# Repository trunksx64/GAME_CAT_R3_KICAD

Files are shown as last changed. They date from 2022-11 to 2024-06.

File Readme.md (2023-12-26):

# Game//Cat ::: Revisión R3 :: Versión 3.50

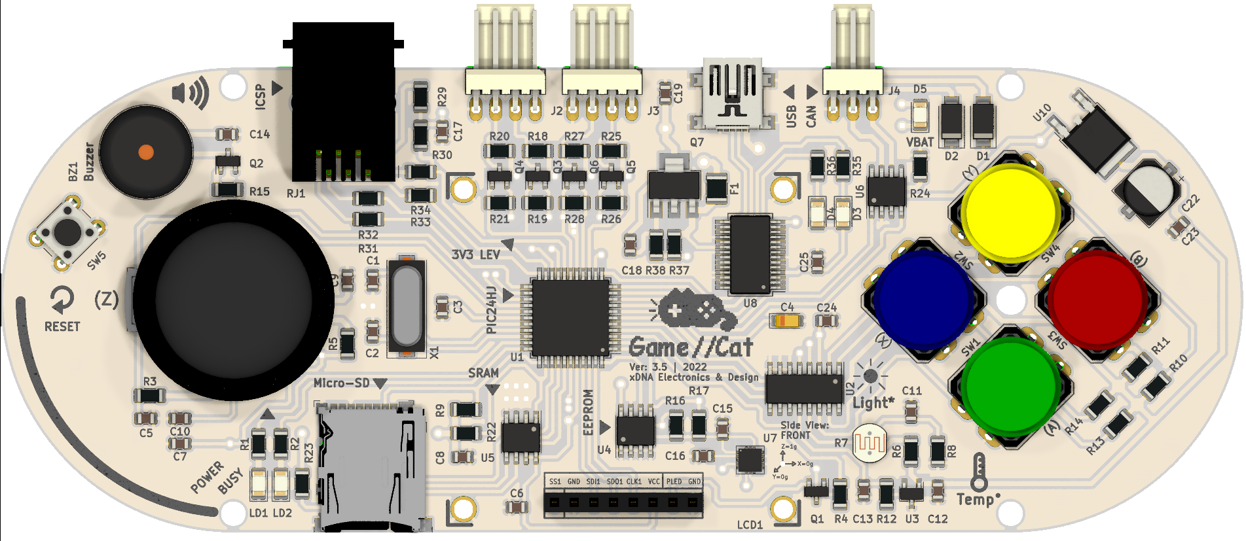
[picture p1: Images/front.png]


## Razón de Ser e Inspiración

Este Control se basa en la Idea Original del Game//Cat Version R2, el cual a su vez se inspira en el diseño del joystick y botones del Arduino Esplora. El primer Control se implementó para ser usado como parametrizador y las siguientes revisiones se presentó como Tesis de Grado de Especialización de Instrumentación Industrial que curse. Se Utilizó principalmente como Herramienta de Programación para Tarjeta de Control de Ascensores Usando Un Firmware de Codito Cerrado. Se Implementó FREERTOS para su uso, así como librerías Básicas en MPLABX y XC16. La idea principal es utilizar los Microcontroladores de 16Bits de Microchip con periféricos listos y configurados. Es pequeño y Portable, ideal para llevar a todo lado, no intenta competir con controles similares a Arduino. Se desea implementar a futuro un Bootloader tanto por USB, RS232, SD y CAN.

Inicialmente, se Requiere un Programador Basado en PICKIT2/ICD3, MPLAB C30 Y MPLAB V4.0 como mínimo. 

En la Actualidad se recomienda el MPLAB SNAP, XC16 y MPLABX V6.0 

Algunos Elementos "Footprints" y "Symbols" están basados en mis librerías, cuáles encontrarán en este mismo Repositorio.

## Características del Hardware

  * Microcontrolador PIC24HJ128GP504.
  * Pantalla LCD PCD8544 (Based Nokia GLCD) - SPI.
  * Joystick Análogo de 2 ejes + Botón Digital.
  * 4 Botones Digitales.
  * Accelerometro - MMA8452Q - I2C. 
  * Sensor de Temperatura (LM61).
  * Sensor de Luz (LDR).
  * Memoria Eeprom 24LCXXX - I2C.
  * Memoria Ram 23KXX - SPI.
  * Ranura Memoria Micro-SD - SPI.
  * Buzzer por PWM.
  * Conexión USB - FTDI-RL232/UART - 5V.
  * Conexión CAN 5V.
  * 2 LED´s de Actividad.
  * Salidas Para PWM y UART - Con figurables - 3.3V.
  * Conexión ICSP con línea AUX, para control extra de puerto.
  * Cargador de Batería Lipo (MCP73831) con Indicador LED.

## Características Específicas

  * Debido a que el PIC trabaja a 3.3V, el uso del PCA82C251 y el FTDI-RL232 está a 5V, alimentado directamente por el Control USB, el FTDI-RL232 se encarga de "gestionar" la alimentación del sistema proporcionando un arranque suave en la tensión, luego se pasa por un regulador de 3,3V para alimentar el resto de componentes.
  * Para Potabilidad he agregado un control para la carga de Baterías de tipo Lipo, este gobernado él con el CI MCP73831, el cual mediante el uso del Mosfet DMP1045, intercambia la alimentación proveniente del FTDI-RL232 y la Batería según el estado de conexión USB, se puede usar Baterías de 3,7V en adelante hasta un máximo de 6V, cuando el Game//Cat está usando la Batería, el FTDI-RL232 se deshabilita.
  * Para el Manejo del Joystick, Botones, Sensor de Temperatura y Luz. He empleado el CI-74HC4051, que es un Multiplexor Análogo para leer los Valores por el módulo ADC, el cual puede utilizarse de 10 o 12Bits en conjunto con un canal DMA si fuere necesario.
  * La Comunicación UART, es una Salida/Entrada dedicada con un conversor de tensión de 3.3V a 5V de forma bidireccional con transistores Mosfet, con el fin de proteger y poder comunicar el PIC24H con cualquier tipo de dispositivo.
  * La Comunicación USB se hace por medio del CI FTDI-RL232, esto es porque el PIC no posee dicho Módulo y además permite ahorrar en la Memoria del PIC el Stack del USB, esto permite que sea Conectar y Usar, puesto que los Drives de este USB son reconocidos de forma inmediata por Windows y Linux sin problemas.
  * La Comunicación CAN la he Incluido porque en estos momentos trabajo con esta interfase y su popularidad ha crecido bastante, por experiencia este BUS es muy robusto y fácil de usar, en el PIC se hace uso de dos canales DMA teniendo una respuesta bastante rápida y sin sacrificar la memoria RAM principal, su conexión se hace por medio del Transeiver PCA82C251, además he agregado un par de diodos TVH para proteger dicho CI.
  * La Ranura para la Tarjeta Micro-SD, posee conexión con el Módulo SPI, el cual está compartida con la Memoria Ram 23Kxxx, Además la pantalla posee también una conexión al segundo Módulo SPI, que puede usarse para "colgar" otros dispositivos si no vamos a usar la Pantalla.
  * El control del Buzzer se ha dejado por un Pin que puede ser utilizado tanto por el módulo PWM o un pin Común, su uso dependerá del Programa o Aplicación.
  * Posee una Memoria I2C en conjunto con un Accelerometro, con comunicación directa.
  * La programación se hace por medio de la conexión ICSP o Bootloader por USB, usando cualquier programador, PICKIT2-3 y/ó ICD2-3, igual estas salidas pueden usarse como cualquier puerto, teniendo presente que no poseen ninguna protección a tensiones superiores de 3,3V.
  * Ya por Último, he dejado dos visualiza-dores, que son libres de uso.

Básicamente, esto es el GAME//CAT, una tarjeta más que un sistema de control para usuarios avanzados, es una tarjeta de entrenamiento para los principiantes, puesto que todo lo que incluye hace uso forzoso de todo los controles que el PIC24HJ128GP504 incorpora.

## Microcontrolador

* Architecture 16-bit.
* CPU Speed Max. 40 MIPS.
* Memory Type Flash.
* Program Memory 128Kb.
* RAM 8,192 Bytes.
* Temperature Range C -40 to 150.
* Operating Voltage Range (V) 3 to 3.6.
* I/O Pins 35 & Pin Count 44.
* Internal Oscillator 7.37 MHz, 32.768 kH.
* Digital Communication Peripherals 2-UART, 2-SPI,1-I2C, 1-CAN.
* Comparators 2, Capture/Compare/PWM Peripherals 4/4, PWM Resolution bits 16.
* Timers 5 x 16-bit 2 x 32-bit.
* Parallel Port PMP(No Usado), Hardware RTCC-1 (No Usado).
* Chanel DMA-8.
* Cap Touch Channels-13 (No Usado).

## Versiones

* 2017 : 1.0.0 : Primera Versión en Kicad 4
* 2017 : 1.2.0 : Se Agregó Conversión de Tensión 5V a 3.3V Bidireccional en salida UART y PWM, se eliminó conexión DC externa.
* 2018 : 2.0.0 : Se Migró completamente a Kicad 5, el Led control se removió para dar opción de selección de Periférico SPI (Ram y SD).
* 2018 : 2.1.0 : Se rediseñó y corrigió error en botón del Joystick, se corrigió el trucado de líneas de Programación PGM y PGD.
* 2018 : 2.2.0 : Se Agregó Resistencias de protección (0Ohm) en entradas Jack RJ11 de Programación.
* 2018 : 2.1.0 : Se Agregó y Calibro Resistencia del Botón de Reset, se agregó control se Carga para Bateria Lipo 3.3V.
* 2018 : 2.5.0 : Se Actulizaron Logos de la Marca y de Hardware Libre, se Actualizó a licencia Creative Commons V4.
* 2018 : 2.7.0 : Se Actualizaron las Librerías de Módulos de Kicad, basadas en Progetti Walter.
* 2018 : 2.9.0 : Se Agregaron condensadores de filtrado al multiplexor análogo, se cambiaron los botones por diseño con poste.
* 2019 : 2.9.1 : Se Organizaron los Archivos para Hospedarlos en Github, Se Ordenaron condensadores y Cristal del PIC.
* 2021 : 2.9.1 : Se Actualiza a KiCad 6 todos los archivos y Librerías.
* 2022 : 3.0.0 : Se Actualizaron los Valores de las resistencias del conversor de 5V-3.3V de un 1K a 10K.
* 2022 : 3.1.0 : Se reestructuró completamente los esquemáticos y se usaron páginas separadas para cada Módulo.
* 2022 : 3.2.0 : Se corrigieron errores en los anchos de pista y reubicaron varios elementos como Seregrafia.
* 2022 : 3.3.0 : Se Actualizaron los conectores Moles para cuatros Salidas, sumando VCC y GND para alimentar controles externos.
* 2022 : 3.5.0 : Se Actualizaron los Logos y posiciones de Seregrafia de Varios componentes.

## ERRATAS

* Debido a tolerancia de tensión del MCP2551, no es posible usarlo para tensiones de 3.3V, cuál hacer imposible usar el CANBUS, sé recomienda usar el PCA82C251 cuál soportar desde 1.8V hasta 24V.

## Créditos

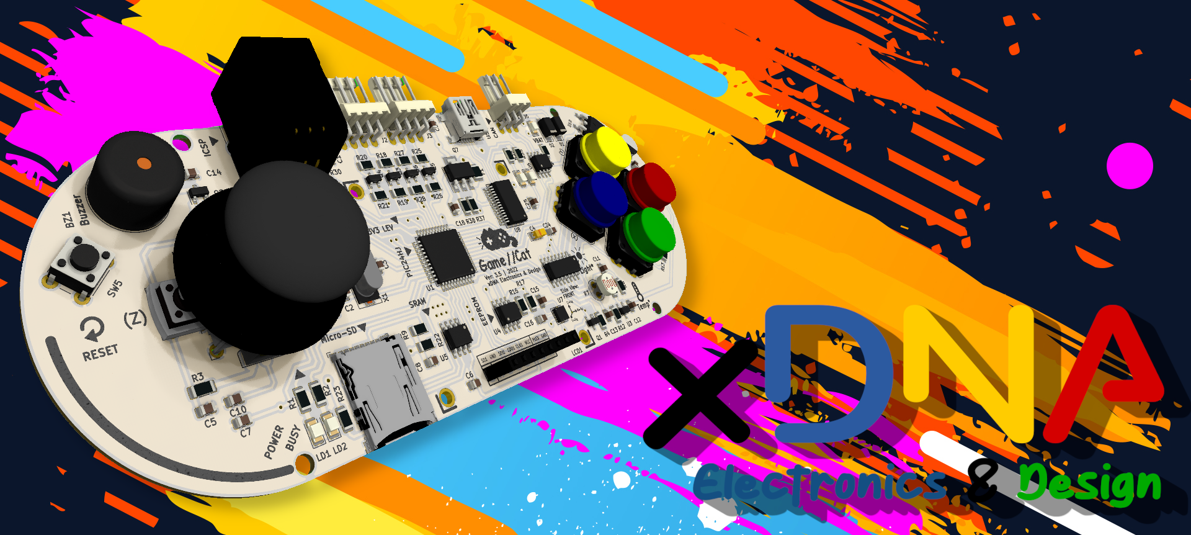
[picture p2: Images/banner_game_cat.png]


xDNA Electronics & Desing es una microempresa Personal, que se dedica y encarga de elaborar proyectos de Control y Automatización por pedido, su idea es colaborar y ayudar a quines a si lo requieran, el proyecto se hizo principalmente como Hobby el cual gracias a terceros se pudo implementar y hacer su creación, por lo cual se da la libertad de usarlo para experimentar sin hacer uso comercial del mismo.

## Licencia

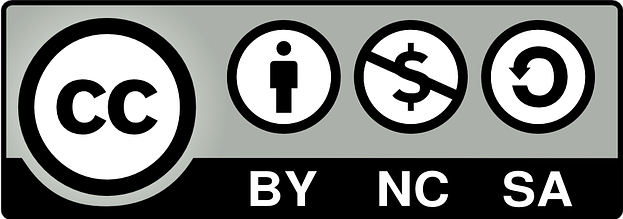
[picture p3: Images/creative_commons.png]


Licensed under Attribution-NonCommercial-ShareAlike 4.0 International (CC BY-NC-SA 4.0)

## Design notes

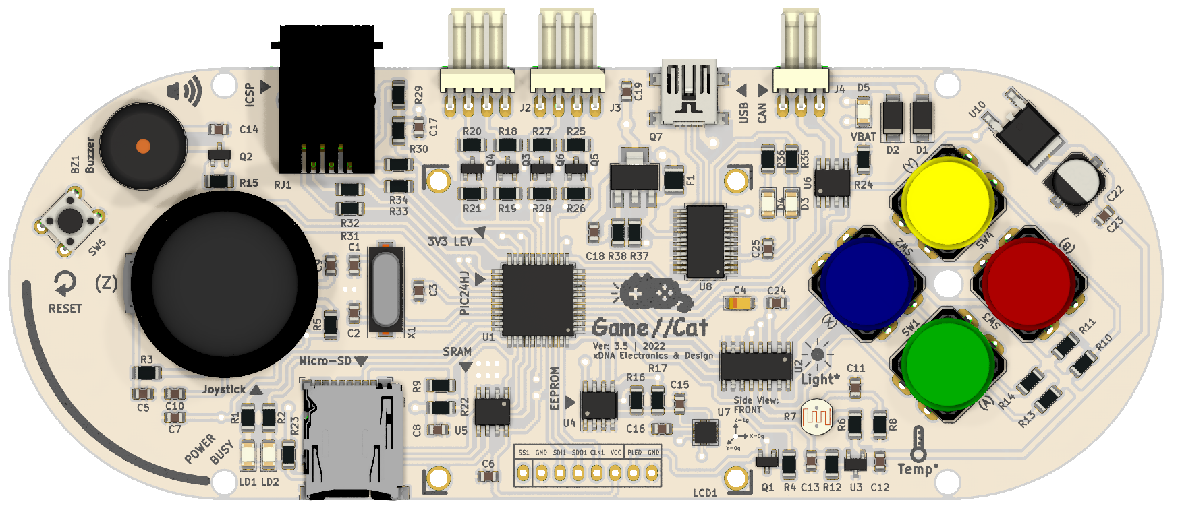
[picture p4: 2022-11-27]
Game_Cat_R3.png

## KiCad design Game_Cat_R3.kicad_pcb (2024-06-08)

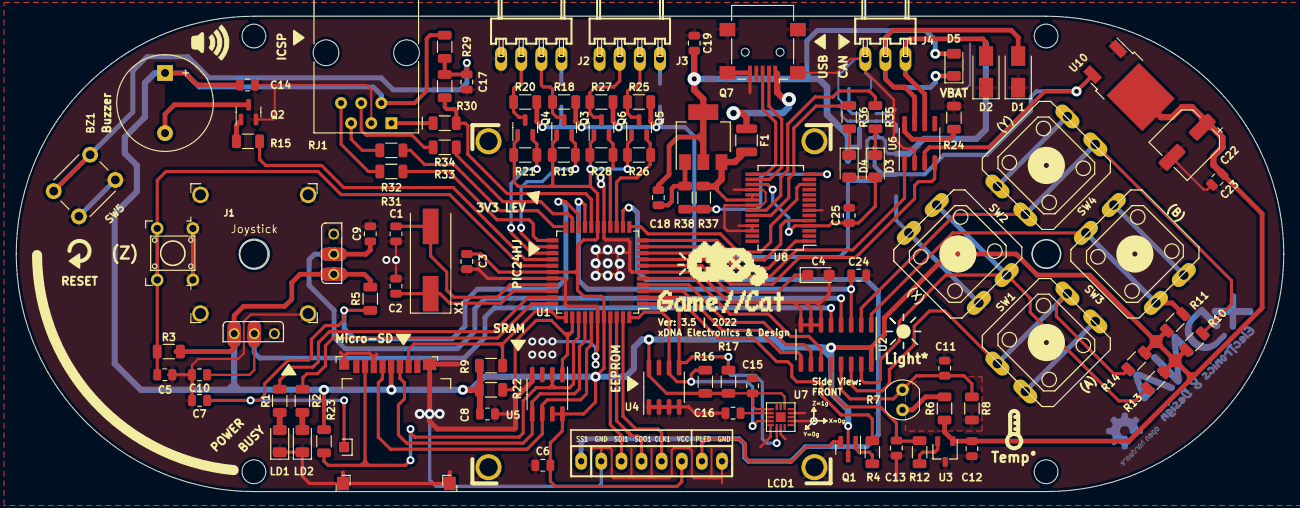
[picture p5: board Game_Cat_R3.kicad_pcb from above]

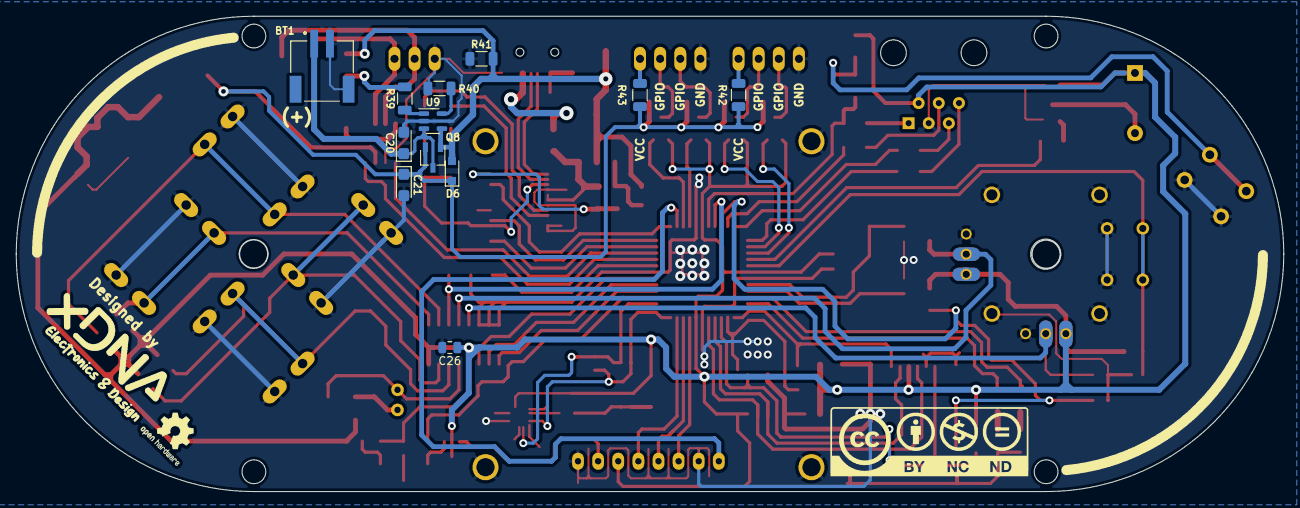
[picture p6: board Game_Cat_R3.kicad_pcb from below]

Board: 2 copper layers, 160.0 x 60.0 mm, 113 parts (12 on the bottom side), 87 nets.

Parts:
BT1: 3V7; Connector_1x02_P2.0mm
BZ1: Buzzer; Buzzer_12x9.5RM7.6
C1, C2: 22pF; C_0805_2012Metric
C3, C25: 100uF; C_0805_2012Metric
C4: 10uF; CP_EIA-3216-18_Kemet-A
C5, C7, C9, C10, C24, C26: 10pF; C_0805_2012Metric
C6, C8, C11, C12, C14, C15, C16: 10nF; C_0805_2012Metric
C13, C17, C18, C19, C23: 100nF; C_0805_2012Metric
C20: 4.7uF; CP_EIA-3216-18_Kemet-A
C21: 1uF; CP_EIA-3216-18_Kemet-A
C22: 100uF; CP_Elec_6.3x4.5
D1, D2: D_TVS; D_SMA
D3, D4: LED; LED_1206_3216Metric
D5: VBAT; LED_1206_3216Metric
D6: BAT60J; D_SOD-323_HandSoldering
F1: Fuse; R_1210_3225Metric
J1: Joystick; JOYSTICK_TUMB
J2: UART; MOLEX_KK_1x04_P2.54mm_HORIZONTAL
J3: PWM; MOLEX_KK_1x04_P2.54mm_HORIZONTAL
J4: CAN; MOLEX_KK_1x03_P2.54mm_HORIZONTAL
LCD1: PCD8544-BASE; GLCD_PCD8544_BASE
LD1: POWER; LED_1206_3216Metric
LD2: BUSY; LED_1206_3216Metric
Q1: MMBT3906; SOT-23
Q2: MMBT3904; SOT-23
Q3, Q4, Q5, Q6: BSS138; SOT-23
Q7: IRFL901; SOT-223
Q8: NTR1P02LT1G; TSOT-23
R1, R2, R35: 330R; R_1206_3216Metric
R3, R4, R5, R6, R8, R10, R11, R12, R13, R14, R18, R19, R20, R21, R25, R27, R28, R29, R37, R40: 10K; R_1206_3216Metric
R7: VT93xx; R_LDR_4.9x4.2mm_P2.54mm_Vertical
R9, R15, R22, R23, R24, R26, R38, R42, R43: 1K; R_1206_3216Metric
R16, R17: 4K7; R_1206_3216Metric
R30, R39: 470R; R_1206_3216Metric
R31, R32, R33, R34: 0R; R_1206_3216Metric
R36: 33OR; R_1206_3216Metric
R41: 100K; R_1206_3216Metric
RJ1: RJ12; RJ12_Horizontal
Ref**: GameCatPixel; xdna_game_cat_logo_skill_pixel
SD1: Micro-SD; MICRO_SD_HC_DM3AT
SW1: (A); SW_PUSH_PTS_125x12mm_SNAP_GREEN
SW2: (X); SW_PUSH_PTS_125x12mm_SNAP_BLUE
SW3: (B); SW_PUSH_PTS_125x12mm_SNAP_RED
SW4: (Y); SW_PUSH_PTS_125x12mm_SNAP_YELLOW
SW5: RESET; SW_PUSH_6mm_H5mm
U1: PIC24HJXXXGPX04_TQFP; TQFP-44_10x10mm_P0.8mm
U2: 74HC4051; SOIC-16_3.9x9.9mm_P1.27mm
U3: LM61; TSOT-23
U4: M24C512; SOIC-8_3.9x4.9mm_P1.27mm
U5: 23KXX; SOIC-8_3.9x4.9mm_P1.27mm
U6: PCA82C251; SOIC-8_3.9x4.9mm_P1.27mm
U7: MMA8452Q; QFN_16_3x3x1mm_P0.5mm
U8: FT232RL; SSOP-28_5.3x10.2mm_P0.65mm
U9: MCP73831; SOT-23-5
U10: LM1117; TO-252-2
USB1: USB_B_Micro; USB_Mini-B_Lumberg_2486_01_Horizontal
X1: 4Mhz; Crystal_SMD_HC49-SD

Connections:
+3.3VA: D3.2 (A), D4.2 (A), U8.4 (VCCIO), U8.17 (3V3OUT)
+3V3: BZ1.1 (-), C3.1, C6.1, C8.1, C12.1, C14.1, C15.1, C22.1, C23.2, C26.1, J1.1 (V+), J1.4 (H+~), LCD1.6 (VCC), Q1.3 (C), Q3.1 (G), Q4.1 (G), Q5.1 (G), Q6.1 (G), R3.2, R5.2, R6.1, R9.1, R10.1, R11.1, R13.1, R14.1, R16.1, R17.1, R19.2, R21.2, R22.1, R23.1, R26.2, R28.2, R29.2, RJ1.2, SD1.4 (VDD), U1.17 (AVDD), U1.28 (VDD), U1.40 (VDD), U2.16 (VCC), U3.1 (VCC), U4.8 (VCC), U5.7 (HOLD), U5.8 (VDD), U7.1 (VDDIO), U7.14 (VDD), U10.2 (VO)
+5C: C21.1, D6.1 (K), Q8.2 (S), R18.1, R20.1, R25.1, R27.1, R42.1, R43.1, U6.3 (VCC), U10.3 (VI)
+5V: F1.2, Q7.3 (S), R37.2, U8.19 (~RESET), U8.20 (VCC)
/BUTTONS/Axis(X): C10.1, J1.2 (V), U2.5 (A5)
/BUTTONS/Axis(Y): C9.1, J1.5 (H), U2.4 (A7)
/BUTTONS/Button(A): R14.2, SW1.1, SW1.2, U2.14 (A1)
/BUTTONS/Button(B): R11.2, SW3.1, SW3.2, U2.1 (A4)
/BUTTONS/Button(X): R13.2, SW2.1, SW2.2, U2.15 (A2)
/BUTTONS/Button(Y): R10.2, SW4.1, SW4.2, U2.2 (A6)
/BUTTONS/CANH: D1.2 (A2), J4.2, U6.7 (CAN+)
/BUTTONS/CANL: D2.2 (A2), J4.1, U6.6 (CAN-)
/BUTTONS/Light: C11.1, R7.2, R8.1, U2.13 (A0)
/BUTTONS/Temp: C13.2, R12.1, U2.12 (A3)
/MICROCONTROLLER/VCAP: C4.1, U1.7 (VCAP)
/POWER_SUPPLY/BAT: BT1.1 (+), C20.1, Q8.3 (D), U9.3 (VBAT)
/POWER_SUPPLY/CBUS0: R36.1, U8.23 (CBUS0)
/POWER_SUPPLY/CBUS1: R35.1, U8.22 (CBUS1)
/POWER_SUPPLY/PWREN: R37.1, R38.2, U8.14 (CBUS3)
ADC-IN: C24.1, U1.19 (RA0/CN2/VREF+/AN0), U2.3 (A)
AUX_ICD: R31.2, U1.23 (AN4/C1IN-/RP2/CN6/RB2)
BUTTON_Z: C5.1, J1.7 (B+), R3.1, U1.27 (RC2/CN10/PMA2/RP18/CVREF/AN8)
BUZZER: R15.1, U1.26 (RC1/CN9/RP17/AN7)
CHECK-SD: C7.1, R5.1, U1.20 (RA1/CN3/VREF-/AN1)
GLCD_LED: R4.1, U1.2 (RC6/PMA1/CN18/RP22)
GND: BT1.2 (-), C1.2, C2.1, C3.2, C4.2, C5.2, C6.2, C7.2, C8.2, C9.2, C10.2, C11.2, C12.2, C13.1, C14.2, C15.2, C16.2, C17.1, C19.1, C20.2, C21.2, C22.2, C23.1, C24.2, C25.2, C26.2, D1.1 (A1), D2.1 (A1), J1.3 (V-), J1.6 (H-), J1.8 (B-), J1.9 (SHIELD), J2.4, J3.4, J4.3, LCD1.2 (SCE), LCD1.8 (GND), LD1.1 (K), LD2.1 (K), Q2.2 (E), R8.2, R24.1, R40.1, R41.1, RJ1.3, SD1.6 (VSS), SW1.3 (K), SW1.4 (A), SW2.3 (K), SW2.4 (A), SW3.3 (K), SW3.4 (A), SW4.3 (K), SW4.4 (A), SW5.1, U1.6 (VSS), U1.16 (AVSS), U1.29 (VSS), U1.39 (VSS), U2.6 (~E), U2.7 (VEE), U2.8 (GND), U3.3 (GND), U4.1 (E0), U4.2 (E1), U4.3 (E2), U4.4 (VSS), U4.7 (~WC), U5.4 (VSS), U6.2 (GND), U7.5 (GND), U7.7 (SAO), U7.10 (GND), U7.12 (GND), U8.7 (GND), U8.18 (GND), U8.21 (GND), U8.25 (AGND), U8.26 (TEST), U9.2 (VSS), U10.1 (GND), USB1.5 (GND), USB1.6 (Shield)
I2C_SCL: R16.2, U1.44 (SCL1/RP8/CN22/PMD4/RB8), U4.6 (SCL), U7.4 (SCL)
I2C_SDA: R17.2, U1.1 (SDA1/RP9/CN21/PMD3/RB9), U4.5 (SDA), U7.6 (SDA)
MISO_GLCD: LCD1.3 (DC), U1.41 (PGED3/ASDA1/RP5/CN27/PMD7/RB5)
MISO_MEN: R23.2, SD1.7 (DO), U1.36 (RC3/PMBE/CN28/RP19), U5.2 (SO)
MOSI_GLCD: LCD1.4 (DIN), U1.42 (PGEC3/ASCL1/RP6/CN24/PMD6/RB6)
MOSI_MEN: SD1.3 (DI), U1.37 (RC4/PMA4/CN25/RP20), U5.5 (SI)
MUX_A: U1.5 (RC9/PMA6/CN19/RP25), U2.11 (S0)
MUX_B: U1.4 (RC8/PMA5/CN20/RP24), U2.10 (S1)
MUX_C: U1.3 (RC7/CN17/PMA0/RP23), U2.9 (S2)
unnamed: BZ1.2 (+), Q2.3 (C)
unnamed: C1.1, U1.30 (RA2/CN30/CLKI/OSC1), X1.2
unnamed: C2.2, U1.31 (RA3/CN29/CLKO/OSC2), X1.1
unnamed: C16.1, U7.2 (BYP)
unnamed: C17.2, R29.1, R30.1, SW5.2
unnamed: C18.1, C19.2, D5.2 (A), D6.2 (A), Q7.2 (D), Q8.1 (G), R41.2, U9.4 (VDD)
unnamed: C18.2, Q7.1 (G), R38.1
unnamed: D3.1 (K), R35.2
unnamed: D4.1 (K), R36.2
unnamed: D5.1 (K), R39.2
unnamed: F1.1, USB1.1 (VBUS)
unnamed: J2.1, R42.2
unnamed: J2.2, Q3.3 (D), R18.2
unnamed: J2.3, Q4.3 (D), R20.2
unnamed: J3.1, R43.2
unnamed: J3.2, Q5.3 (D), R25.2
unnamed: J3.3, Q6.3 (D), R27.2
unnamed: LCD1.7 (LED), Q1.2 (E)
unnamed: LD1.2 (A), R1.2
unnamed: LD2.2 (A), R2.2
unnamed: Q1.1 (B), R4.2
unnamed: Q2.1 (B), R15.2
unnamed: R1.1, U1.32 (RA8/PMA8/TDO)
unnamed: R2.1, U1.33 (SOSCI/RP4/CN1/RB4)
unnamed: R6.2, R7.1
unnamed: R12.2, U3.2 (Vo)
unnamed: R24.2, U6.8 (Rsl)
unnamed: R31.1, RJ1.6
unnamed: R32.1, RJ1.5
unnamed: R33.1, RJ1.4
unnamed: R34.1, RJ1.1
unnamed: R39.1, U9.1 (STAT)
unnamed: R40.2, U9.5 (PROG)
unnamed: U8.15 (USBD+), USB1.3 (D+)
unnamed: U8.16 (USBD-), USB1.2 (D-)
PGC_ICD: R32.2, U1.22 (PGEC1/AN3/C2IN+/RP1/CN5/RB1)
PGD_ICD: R33.2, U1.21 (PGED1/AN2/C2IN-/RP0/CN4/RB0)
RESET_CTRL: R30.2, R34.2, U1.18 (MCLR)
RX_CAN: U1.8 (PGED2/EMCD2/RP10/CN16/PMD2/RB10), U6.4 (RxD)
RX_UART_A: Q4.2 (S), R21.1, U1.25 (RC0/CN8/RP16/AN6)
RX_UART_B: Q6.2 (S), R28.1, U1.15 (AN9/RP15/CN11/PMCS1/RB15)
RX_USB: U1.10 (AN12/RP12/CN14/PMD0/RB12), U8.1 (TXD)
SCK_GLCD: LCD1.5 (CLK), U1.43 (INT0/RP7/CN23/PMD5/RB7)
SCK_MEM: SD1.5 (SCLK), U1.38 (RC5/PMA3/CN26/RP21), U5.6 (SCK)
SLEEP_USB: U1.12 (RA10/PMA10/TMS), U8.12 (CBUS4)
SS_GLCD: LCD1.1 (RES), U1.13 (RA7/PMA7/TCK)
SS_RAM: R22.2, U1.35 (RA9/PMA9/TDI), U5.1 (CS)
SS_USD: R9.2, SD1.2 (CS), U1.34 (RA4/CN0/T1CK/SOSCO)
TX_CAN: U1.9 (PGEC2/RP11/CN15/PMD1/RB11), U6.1 (TxD)
TX_UART_A: Q3.2 (S), R19.1, U1.24 (AN5/C1IN+/RP3/CN7/RB3)
TX_UART_B: Q5.2 (S), R26.1, U1.14 (AN10/RTCC/RP14/CN12/PMWR/RB14)
TX_USB: U1.11 (AN11/RP13/CN13/PMRD/RB13), U8.5 (RXD)
